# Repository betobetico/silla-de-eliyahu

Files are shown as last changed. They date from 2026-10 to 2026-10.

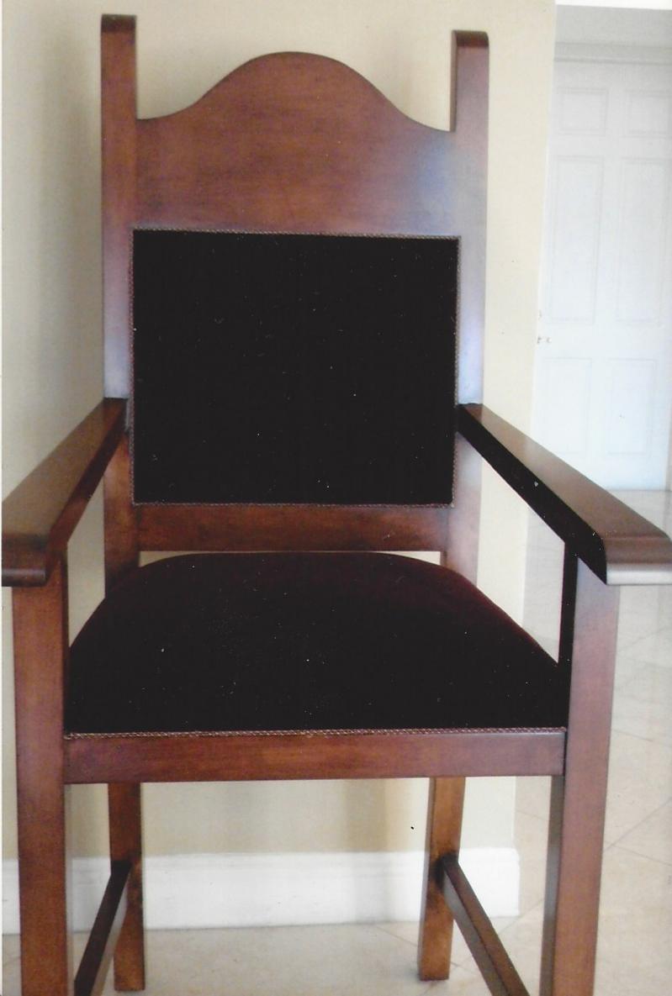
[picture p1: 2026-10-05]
plano/original/foto-frente.jpg

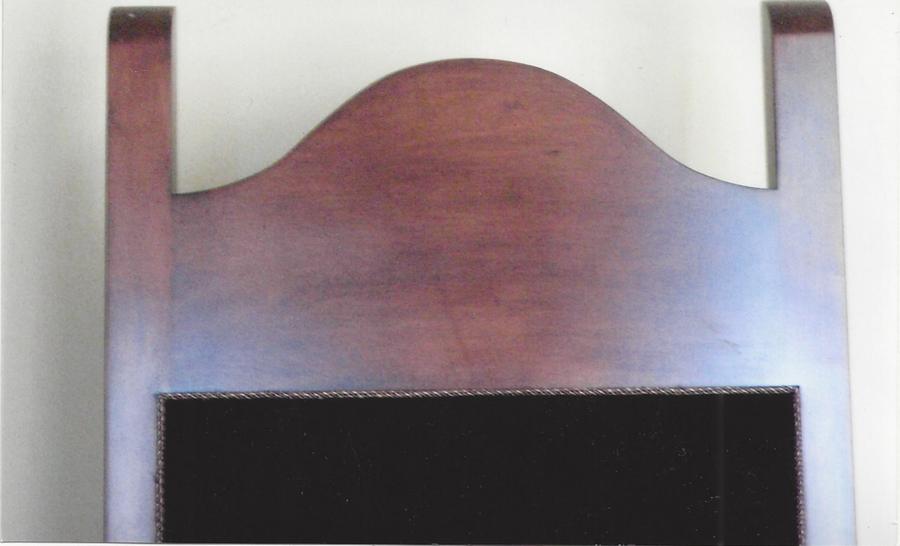
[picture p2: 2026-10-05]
plano/original/foto-copete.jpg

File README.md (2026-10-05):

# La silla de Eliyahu de Isaac Garzón Serfaty z”l

> זה כסא אליהו הנביא זכור לטוב
> *Esta es la silla del profeta Elías, recordado para bien.*

En cada brit milá se reserva una silla para el profeta Eliyahu. Isaac Garzón Serfaty z”l, «tito Isaque», quería hacer sillas como esta para que cada sinagoga pudiera tener la suya. Dejó el plano dibujado a lápiz. Este repositorio lo pasa a CAD para que cualquiera pueda llevárselo a un carpintero.

**Web: [sillaeliyahu.vercel.app](https://sillaeliyahu.vercel.app)** · [English](README.en.md)

> **Antes de cortar**, que un carpintero revise el plano y las seis cotas por validar de [`plano/DUDAS.md`](plano/DUDAS.md). Las medidas salen del dibujo a lápiz de Isaac y de dos fotos: la silla donada todavía no se ha medido.

## Descargas

| Fichero | Para qué |
|---|---|
| [`plano/silla-de-eliyahu.dxf`](plano/silla-de-eliyahu.dxf) | AutoCAD, LibreCAD, FreeCAD… Alzado, vista lateral, planta y copete, acotados en centímetros a escala 1:1 |
| [`plano/silla-de-eliyahu.pdf`](plano/silla-de-eliyahu.pdf) | Tres hojas A3 para imprimir: vistas a 1:10, detalles a 1:4 y despiece |
| [`plano/despiece.csv`](plano/despiece.csv) | Lista de cortes: pieza, cantidad, sección, largo visible y largo de corte con las espigas |
| [`plano/silla.json`](plano/silla.json) | Las medidas de cada pieza: la fuente de la que sale todo lo demás |
| [`plano/DUDAS.md`](plano/DUDAS.md) | **Las cotas que hay que revisar antes de cortar** |
| [`plano/original/`](plano/original/) | Los escaneos: el plano a lápiz de Isaac, la plantilla de las letras y dos fotos de una silla hecha |

## Medidas principales

| | cm |
|---|---|
| Alto total | 164,5 (ver D1) |
| Asiento | 70 (78 con el cojín) |
| Brazos | 101 detrás · 95 en la punta · vuelan 10 por delante de la pata |
| Ancho · fondo | 65 · 59 (69 con los brazos) |
| Postes y patas | 5 × 5 |
| Chambranas y travesaños | 5 × 3 |
| Brazos | 8 × 4 |
| Copete | 26 × 3, con la inscripción grabada por delante |
| Reposapiés | 67 × 13 × 2,5, a 12 del suelo, cajeado en las patas |
| Esterillado | listones de 3 × 1 al ras de las chambranas |

Son 37 piezas de 17 tipos. El plano no indica la especie de madera.

## Antes de cortar

El plano de Isaac no lo dice todo. Hay seis puntos en los que faltaba una cota o dos no cuadraban, y en cada uno se ha tomado una decisión. Están explicados en [`plano/DUDAS.md`](plano/DUDAS.md). Los dos que más cambian la silla:

- **D1 · Alto total.** El alzado lateral suma 159 y el trasero, 164,5. Se han respetado las piezas del trasero, con el respaldo de 45,5, y los postes miden 164,5.
- **D6 · Reposapiés.** En el plano va entero por delante de las patas. Como es el escalón natural para subirse a un asiento de 70, pisar su borde puede volcar la silla. Se ha retrasado: queda cajeado en las patas y apoyado en un travesaño.

En el DXF, las letras van en contornos (capa `LETRAS`, en Frank Ruhl Libre), listas para una fresadora o un láser. El texto editable está en la capa `LETRAS_TEXTO`, apagada, porque no todos los programas lo pintan de derecha a izquierda. Para grabar la caligrafía de Isaac, calca la plantilla original.

Si tienes una silla hecha con este plano, sus medidas resolverían las dudas: abre un *issue* con ellas.

## Cómo está hecho

Todo sale de un único fichero de medidas, [`plano/silla.json`](plano/silla.json). Cada pieza lleva su caja en centímetros (`x` ancho, `y` fondo con 0 en la trasera, `z` alto), su sección, sus espigas y el origen de cada cota: `plano` (escrita por Isaac), `deducido` (sale de sumar o restar cotas) o `supuesto` (elegido para que se pueda construir).

```bash
python3 -m venv .venv && .venv/bin/pip install -r plano/requirements.txt
.venv/bin/python plano/generar.py
```

`generar.py` comprueba que las cotas cuadran (alto total, asiento, ancho, fondo, la pata contra el brazo…) y genera el DXF, el PDF, el despiece y `DUDAS.md`. Si una comprobación falla, termina con error.

La web (`web/`, Next.js + three.js) dibuja la silla en 3D a partir del mismo `silla.json`, así que un cambio de medida llega también al dibujo:

```bash
cd web && npm install && npm run dev
```

## Licencia

El plano, las medidas, los dibujos y los textos tienen licencia [CC BY 4.0](https://creativecommons.org/licenses/by/4.0/deed.es): se pueden copiar, modificar y vender, siempre que se cite a **Isaac Garzón Serfaty z”l**. El código tiene licencia MIT ([`LICENSE-CODE`](LICENSE-CODE)). La fuente Frank Ruhl Libre de `plano/fuentes/` tiene licencia SIL OFL 1.1 ([`OFL.txt`](plano/fuentes/OFL.txt)).

## Haz la tuya

Yo no puedo hacer sillas para todo el mundo. Pero cualquiera puede coger este plano, llevárselo a un carpintero y hacer la silla para su sinagoga. Si eso pasa, yo habré cumplido mi parte y tito Isaque, su mitzvá: que haya una silla de Eliyahu en cada brit milá y se pueda cumplir la mitzvá de la circuncisión.

— Alberto Benbunan Garzón, sobrino de Isaac

La silla que se hizo con este plano en 2016-2017 está en la sinagoga Or Hayeladim de Madrid. La historia, con fotos, está en la web.

## Dónde hay una silla de Isaac

| Sinagoga | Ciudad | |
|---|---|---|
| — | Caracas (Venezuela) | Donada por Isaac |
| — | Porlamar, isla de Margarita (Venezuela) | Donada por Isaac |
| Skylake | Miami (Estados Unidos) | Donada por Isaac |
| Or Hayeladim | Madrid (España) | Julio de 2017, hecha con su plano |

Si sabes de otra, o si haces la tuya, [abre un *issue*](https://github.com/betobetico/silla-de-eliyahu/issues/new) y la añadimos.

## Créditos

- Plano y primera silla: Isaac Garzón Serfaty z”l.
- Primer CAD del plano: Acacia Waich. El de este repositorio se ha rehecho a partir del suyo.
- Carpintero de la silla de Or Hayeladim: Mateo Bonilla, que aparece en las fotos del taller. En las de la silla terminada aparece Alberto Benbunan Garzón.
- Las fotos de `web/public/historia/` son de sus autores y no entran en la licencia CC BY.

*En memoria de Isaac Garzón Serfaty z”l.*

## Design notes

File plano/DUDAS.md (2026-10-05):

# Cotas por validar

El plano de Isaac no lo dice todo. Donde faltaba una cota o dos no cuadraban, se ha tomado una decisión.
Este fichero se genera desde `silla.json`: para cambiar algo, edita ese fichero y ejecuta `python plano/generar.py`.

## D1 · Alto total: 159 o 164,5

El alzado lateral suma 20 + 5 + 40 + 5 + 27 + 4 + 58 = 159, que coincide con la cota total que escribió Isaac. El trasero suma 20 + 5 + 40 + 5 + 8 + 8 + 45,5 + 15 + 18 = 164,5. Una de las dos cadenas tiene una cota mal.

- **Se ha hecho:** Se respetan las medidas de las piezas del alzado trasero, con el respaldo de 45,5 como está escrito: los postes miden 164,5 y el «58» del lateral pasa a 63,5. Las proporciones de las fotos encajan mejor con 45,5 que con un respaldo recortado.
- **Alternativa:** Mantener 159 acortando de 18 a 12,5 lo que el poste asoma sobre el hombro del copete. Medir la silla donada lo resuelve

## D2 · Ancho: 65 por fuera

El alzado trasero acota 65 entre las caras exteriores de los postes. El «66 interno» del croquis de los brazos está dibujado a lo largo del brazo: es su largo, no un ancho.

- **Se ha hecho:** 65 por fuera y 55 por dentro. Las fotos dan un interior de ese orden.

## D3 · El vuelo del brazo

El «10» del lateral está entre la cara delantera de la pata y la punta del brazo: el brazo vuela 10 cm. Con «66 interno» como largo, la punta queda entre 7 y 12 cm por delante de la pata. En la foto parece que vuela unos 5.

- **Se ha hecho:** Vuelo de 10 y brazo de 64 visibles desde el poste. Cortar los brazos a 70 y recortar la punta en obra. El ensanche de 8 a 10 en la punta es un supuesto sacado de las fotos.
- **Alternativa:** Vuelo de 5, como parece en la foto

## D4 · Chambrana delantera y esterillado

El plano dice que lleva esterillado al ras de la chambrana, pero no dibuja la chambrana delantera ni cómo se apoyan los listones.

- **Se ha hecho:** Chambrana delantera igual que la trasera y dos listones de 2 × 2 por dentro de las laterales para apoyar 11 listones de 3 × 1 de 55 cm, entre los postes y las patas.
- **Alternativa:** Listones de delante a atrás, apoyados en la chambrana delantera y la trasera

## D5 · Las letras

La plantilla está a tamaño real: los números 32, 26 y 11,5 que la acompañan (69,5 en total) son los largos de las tres filas de la hoja, y a esa escala las letras miden entre 3,5 y 3,9 cm, lo mismo que dice la nota «letras bajas 3,5 cm». La escala se ha deducido así, no medido: el escaneo no trae resolución.

- **Se ha hecho:** Letras de 3,5 cm en dos líneas centradas: la de arriba mide unos 47 cm y la de abajo unos 22, con unos 4 cm de margen a cada lado en los 55 del copete. Antes de grabar, comprobar en papel que la línea de arriba cabe.

## D6 · Reposapiés y vuelco

En el plano el reposapiés va entero por delante de las patas, a 12 del suelo (Isaac escribe 12 y 13: 12 parece la altura y 13 el fondo de la tabla). Es el escalón natural para subirse a un asiento de 70, y si un adulto pisa su borde delantero puede volcar la silla hacia delante.

- **Se ha hecho:** Se retrasa: la tabla va de 7 cm por detrás a 6 cm por delante de la cara de las patas, cajeada alrededor de ellas, sobre un travesaño de 5 × 3 entre las patas y dos ménsulas cortas.
- **Alternativa:** El reposapiés de Isaac, entero por delante, con un travesaño bajo su arista trasera y la advertencia de no subirse por él

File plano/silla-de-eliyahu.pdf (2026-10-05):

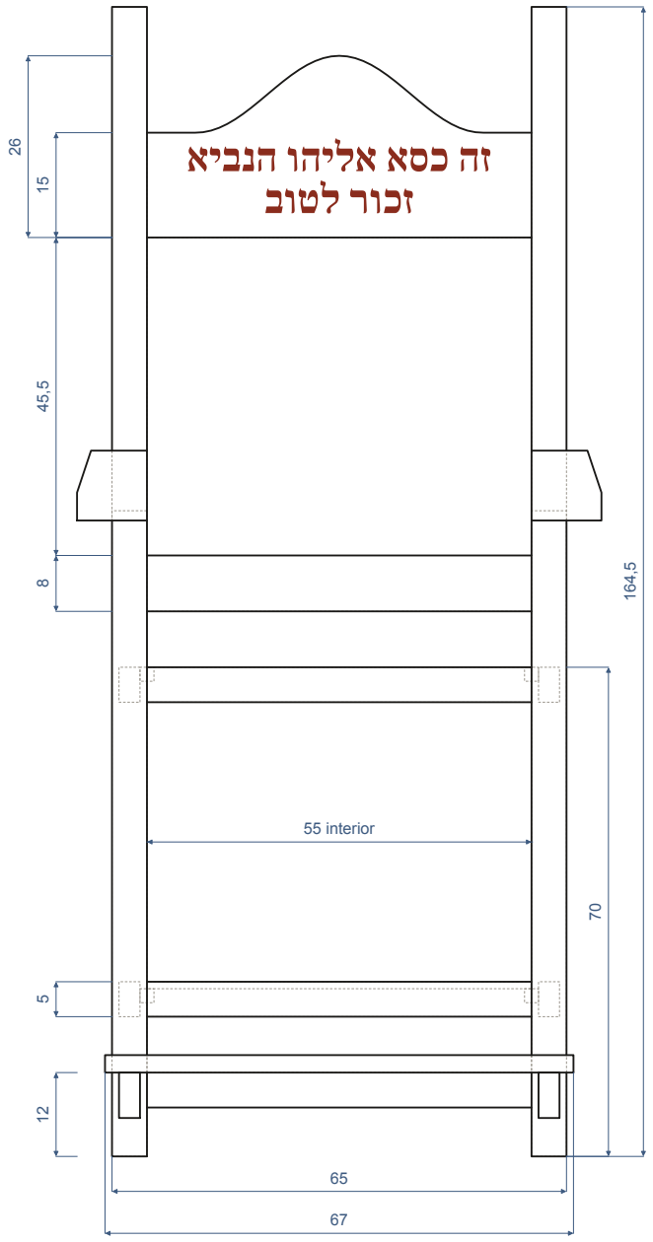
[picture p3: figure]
55 interior

ALZADO FRONTAL

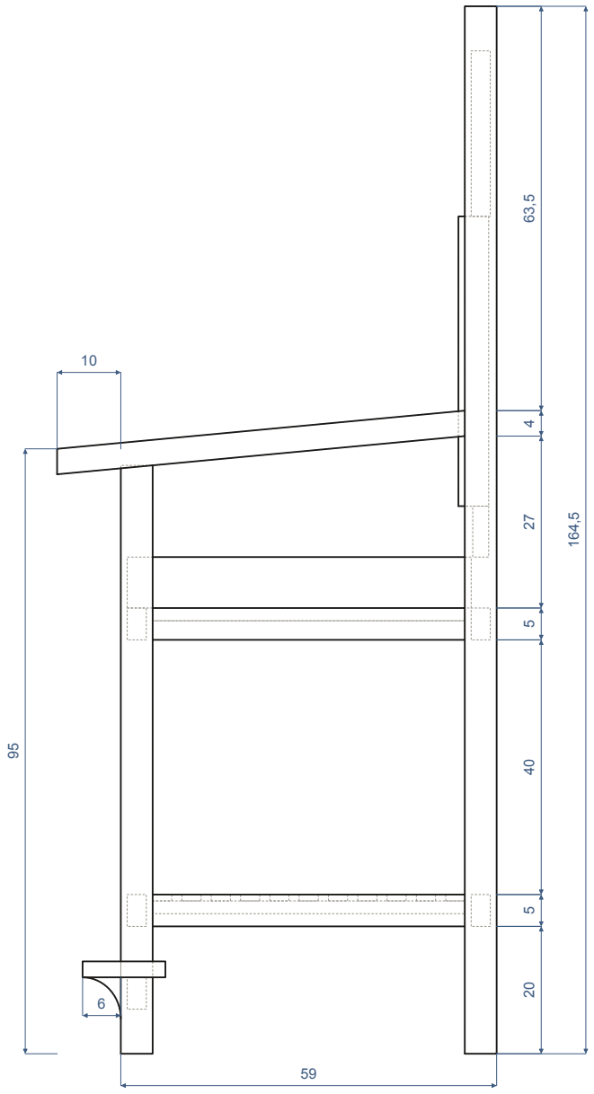
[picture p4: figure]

← FRENTE

VISTA LATERAL

# Silla de Eliyahu (Kisé Eliyahu) de Isaac Garzón Serfaty z”l

Alzado y vista lateral · escala 1:10 en A3 · cotas en cm · sistema europeo

CC BY 4.0 · atribución: Isaac Garzón Serfaty z”l · github.com/betobetico/silla-de-eliyahu

AVISO

Antes de cortar, que un carpintero revise este plano y las seis cotas por validar de la hoja 4. Las medidas de la silla donada todavía no se han tomado.

NOTAS

- Postes y patas 5×5 · chambranas y travesaños 5×3
- Brazos 8×4 · copete 26×3 · travesaño bajo del respaldo 8×2,5
- Reposapiés 67×13×2,5 cajeado en las patas (D6)
- Esterillado de listones 3×1 al ras de las chambranas
- Espigas de 2,5 cm en chambranas, travesaño del respaldo y copete; de 3,5 en travesaños del asiento, brazos y patas. Donde dos espigas entran en el mismo poste a la misma altura, se cortan a inglete. Grueso de espiga: 1 cm en piezas de 3
- Inscripción grabada en la cara delantera del copete: calcar la plantilla original, que está a tamaño real
- Cajas de postes y patas y despiece: hoja 3 · planta y detalles: hoja 2
- Cotas por validar antes de cortar: hoja 4 (D1-D6)

Dibujado a partir del plano a lápiz de Isaac Garzón Serfaty
z”l y del primer CAD, de Acacia Waich. Ante la duda, manda una silla de verdad.

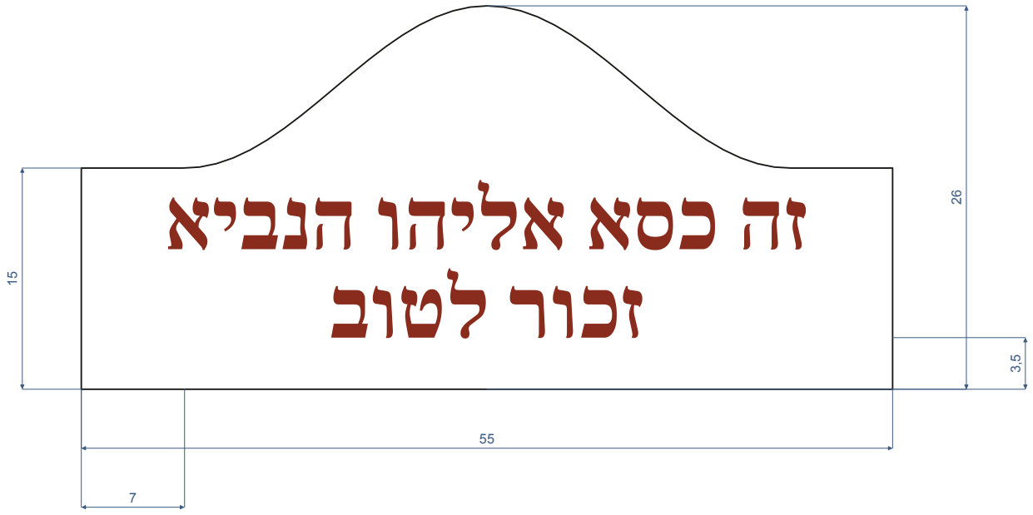
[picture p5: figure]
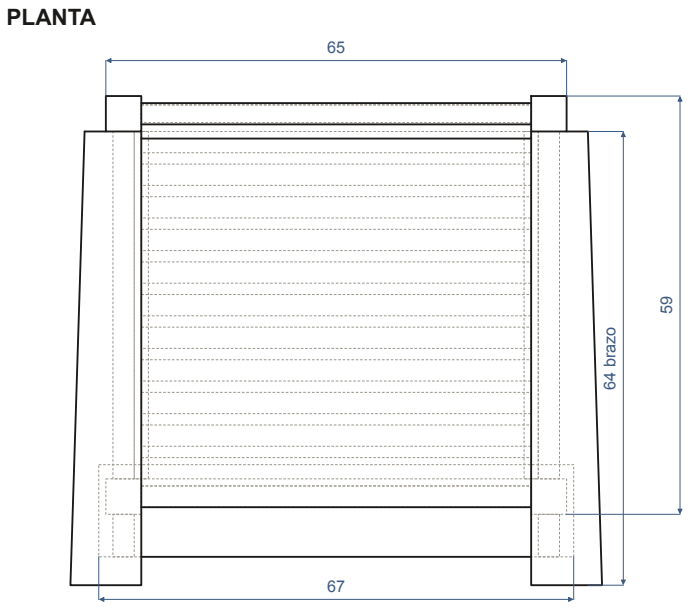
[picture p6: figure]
64 brazo; PLANTA

FRENTE ↓

DETALLE DEL COPETE

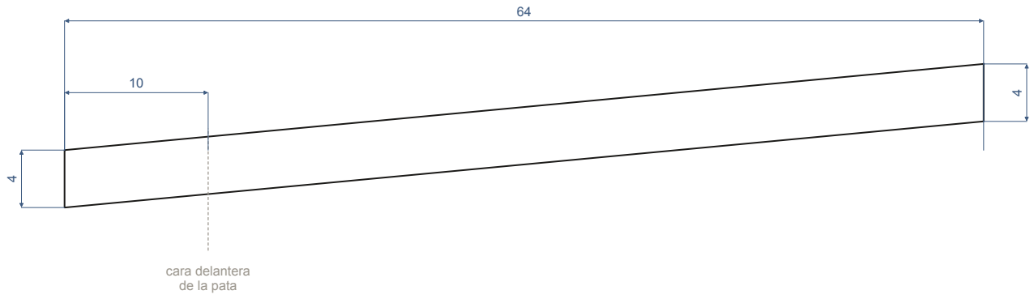
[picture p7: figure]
cara delantera de la pata

8
10

BRAZO · perfil (arriba) y planta (abajo) · la arista recta va hacia dentro

Cortar a 70 y recortar la punta en obra (D3). 101 en el poste, 95 en la punta.

pata

6

6,5

12

13

6

REPOSAPIÉS Y MÉNSULA (D6)

# Planta y detalles

Planta a 1:10 · copete, brazo y ménsula a 1:4 · cotas en cm

chambranas · 20-25

travesaños del asiento · 65-70 travesaño bajo del respaldo · 78-86

brazo · 97-101

copete (hombro) · 131,5-146,5

164,5

POSTE

travesaño del reposapiés · 7-12

chambranas · 20-25

travesaños del asiento · 65-70 92,4

PATA

# Cajas y despiece

Alturas de las cajas en postes y patas a 1:10 · largo de corte = largo visible + espigas

Pieza | Cant. | Sección | Visible | Espiga | Corte | Origen
Poste trasero | 2 | 5 × 5 | 164,5 | — | 164,5 | deducido
Pata delantera | 2 | 5 × 5 | 92,4 | 1 × 3,5 | 95,9 | deducido
Chambrana lateral | 2 | 5 × 3 | 49 | 2 × 2,5 | 54 | plano
Chambrana delantera y trasera | 2 | 5 × 3 | 55 | 2 × 2,5 | 60 | plano / supuesto
Listón del esterillado | 11 | 3 × 1 | 55 | — | 55 | plano
Listón soporte del esterillado | 2 | 2 × 2 | 49 | — | 49 | supuesto
Travesaño lateral del asiento | 2 | 5 × 3 | 49 | 2 × 3,5 | 56 | plano
Travesaño delantero y trasero del asiento | 2 | 5 × 3 | 55 | 2 × 3,5 | 62 | deducido
Listón de apoyo del asiento | 2 | 2 × 2 | 49 | — | 49 | supuesto
Asiento tapizado | 1 | tablero 55 × 54 × 1,5 + espuma | 55 | — | 55 | deducido
Travesaño inferior del respaldo | 1 | 8 × 2,5 | 55 | 2 × 2,5 | 60 | plano
Respaldo tapizado | 1 | tablero 1,5 + espuma | 55 | — | 55 | plano
Copete con dibujo | 1 | 26 × 3 | 55 | 2 × 2,5 | 60 | plano
Brazo | 2 | 8 × 4 | 64,3 | 1 × 3,5 | 70 | plano
Reposapiés | 1 | 13 × 2,5 | 67 | — | 67 | supuesto
Travesaño del reposapiés | 1 | 5 × 3 | 55 | 2 × 2,5 | 60 | supuesto
Ménsula del reposapiés | 2 | 6 × 6,5 × 3 | 6,5 | — | 6,5 | deducido

Espigas de 2,5 cm en chambranas, travesaño del respaldo y copete; de 3,5 en travesaños del asiento, brazos y patas.

Donde dos espigas entran en el mismo poste a la misma altura, se cortan a inglete. Grueso de espiga: 1 cm en piezas de

3.

Además: listones de 2×2 para fijar el respaldo tapizado por detrás, y cuatro escuadras de madera en las esquinas del

bastidor del asiento.

# Cotas por validar antes de cortar

Donde el plano de Isaac no lo dice o dos cotas no cuadran, la decisión tomada y la alternativa

D1 · Alto total: 159 o 164,5

El alzado lateral suma 20 + 5 + 40 + 5 + 27 + 4 + 58 = 159, que coincide con la cota total que escribió Isaac. El trasero suma 20 + 5 + 40 + 5 + 8 + 8 + 45,5 + 15 +

18 = 164,5. Una de las dos cadenas tiene una cota mal.

Se ha hecho: Se respetan las medidas de las piezas del alzado trasero, con el respaldo de 45,5 como está escrito: los postes miden 164,5 y el «58» del lateral pasa a

63,5. Las proporciones de las fotos encajan mejor con 45,5 que con un respaldo recortado.

Alternativa: Mantener 159 acortando de 18 a 12,5 lo que el poste asoma sobre el hombro del copete. Medir la silla donada lo resuelve

D2 · Ancho: 65 por fuera

El alzado trasero acota 65 entre las caras exteriores de los postes. El «66 interno» del croquis de los brazos está dibujado a lo largo del brazo: es su largo, no un

ancho.

Se ha hecho: 65 por fuera y 55 por dentro. Las fotos dan un interior de ese orden.

D3 · El vuelo del brazo

El «10» del lateral está entre la cara delantera de la pata y la punta del brazo: el brazo vuela 10 cm. Con «66 interno» como largo, la punta queda entre 7 y 12 cm

por delante de la pata. En la foto parece que vuela unos 5.

Se ha hecho: Vuelo de 10 y brazo de 64 visibles desde el poste. Cortar los brazos a 70 y recortar la punta en obra. El ensanche de 8 a 10 en la punta es un supuesto

sacado de las fotos.

Alternativa: Vuelo de 5, como parece en la foto

D4 · Chambrana delantera y esterillado

El plano dice que lleva esterillado al ras de la chambrana, pero no dibuja la chambrana delantera ni cómo se apoyan los listones.

Se ha hecho: Chambrana delantera igual que la trasera y dos listones de 2 × 2 por dentro de las laterales para apoyar 11 listones de 3 × 1 de 55 cm, entre los postes

y las patas.

Alternativa: Listones de delante a atrás, apoyados en la chambrana delantera y la trasera

D5 · Las letras

La plantilla está a tamaño real: los números 32, 26 y 11,5 que la acompañan (69,5 en total) son los largos de las tres filas de la hoja, y a esa escala las letras

miden entre 3,5 y 3,9 cm, lo mismo que dice la nota «letras bajas 3,5 cm». La escala se ha deducido así, no medido: el escaneo no trae resolución.

Se ha hecho: Letras de 3,5 cm en dos líneas centradas: la de arriba mide unos 47 cm y la de abajo unos 22, con unos 4 cm de margen a cada lado en los 55 del copete.

Antes de grabar, comprobar en papel que la línea de arriba cabe.

D6 · Reposapiés y vuelco

En el plano el reposapiés va entero por delante de las patas, a 12 del suelo (Isaac escribe 12 y 13: 12 parece la altura y 13 el fondo de la tabla). Es el escalón

natural para subirse a un asiento de 70, y si un adulto pisa su borde delantero puede volcar la silla hacia delante.

Se ha hecho: Se retrasa: la tabla va de 7 cm por detrás a 6 cm por delante de la cara de las patas, cajeada alrededor de ellas, sobre un travesaño de 5 × 3 entre las

patas y dos ménsulas cortas.

Alternativa: El reposapiés de Isaac, entero por delante, con un travesaño bajo su arista trasera y la advertencia de no subirse por él

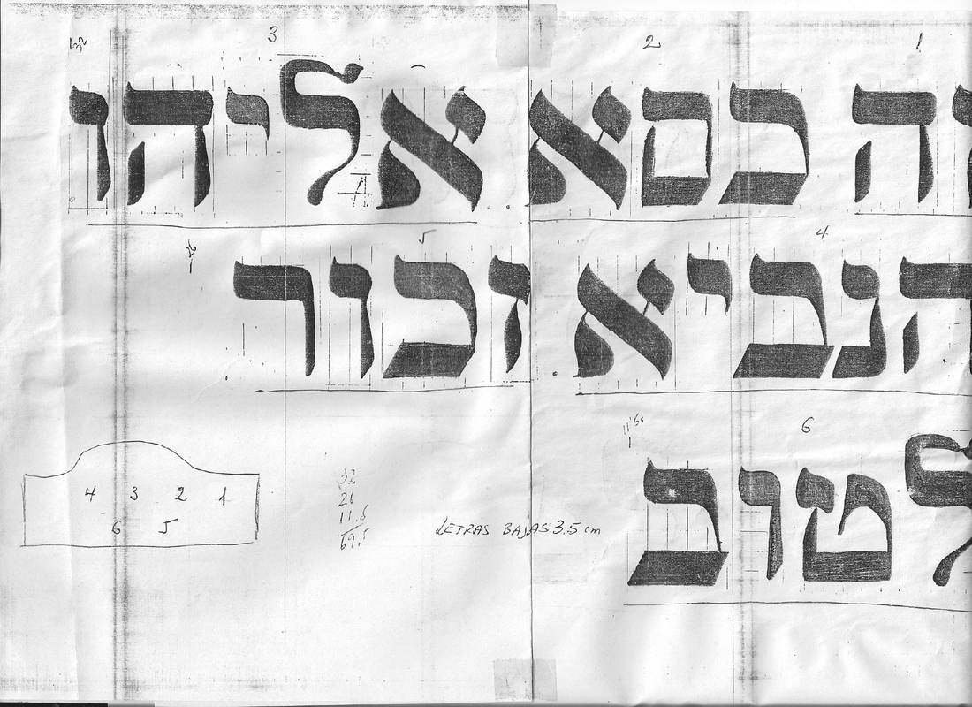
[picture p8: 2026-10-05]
plano/original/plantilla-letras.jpg

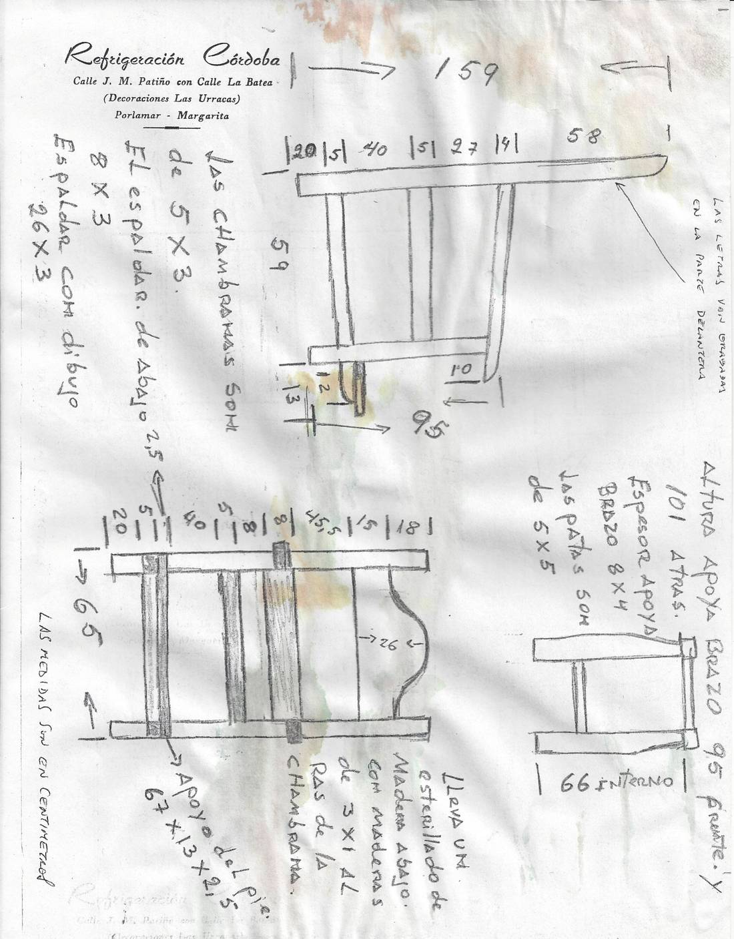
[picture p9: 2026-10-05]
plano/original/plano-isaac.jpg

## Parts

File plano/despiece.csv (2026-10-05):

pieza | piece | cantidad | seccion_cm | largo_visible_cm | largo_corte_cm | espigas | espiga_cm | origen | nota
Poste trasero | Back post | 2 | 5 × 5 | 164.5 | 164.5 | 0 | 0 | deducido | 164,5 de alto (ver D1). Remate superior con la arista delantera redondeada (r ≈ 2 cm)
Pata delantera | Front leg | 2 | 5 × 5 | 92.4 | 95.9 | 1 | 3.5 | deducido | Hombro inclinado como el brazo: 92,4 detrás y 91,9 delante. Mejor con espiga pasante acuñada por la cara de arriba del brazo
Chambrana lateral | Side stretcher | 2 | 5 × 3 | 49 | 54.0 | 2 | 2.5 | plano
Chambrana delantera y trasera | Front and back stretcher | 2 | 5 × 3 | 55 | 60.0 | 2 | 2.5 | plano / supuesto | El plano no la dibuja; hace falta para cerrar el marco del esterillado
Listón del esterillado | Slatted shelf slat | 11 | 3 × 1 | 55 | 55.0 | 0 | 0 | plano | 11 listones de 55 cm, separados 1,6 cm, con la cara de arriba al ras de las chambranas (z = 25)
Listón soporte del esterillado | Shelf cleat | 2 | 2 × 2 | 49 | 49.0 | 0 | 0 | supuesto | Encolado y atornillado por dentro de la chambrana lateral
Travesaño lateral del asiento | Side seat rail | 2 | 5 × 3 | 49 | 56.0 | 2 | 3.5 | plano
Travesaño delantero y trasero del asiento | Front and back seat rail | 2 | 5 × 3 | 55 | 62.0 | 2 | 3.5 | deducido
Listón de apoyo del asiento | Seat cleat | 2 | 2 × 2 | 49 | 49.0 | 0 | 0 | supuesto | Encolado y atornillado por dentro del travesaño lateral del asiento
Asiento tapizado | Upholstered seat | 1 | tablero 55 × 54 × 1,5 + espuma | 55 | 55.0 | 0 | 0 | deducido | Tablero de contrachapado de 1,5 sobre los travesaños delantero y trasero y sobre dos listones de apoyo; espuma y tapizado hasta z = 78. Se recomiendan cuatro escuadras de madera en las esquinas del bastidor
Travesaño inferior del respaldo | Lower back rail | 1 | 8 × 2,5 | 55 | 60.0 | 2 | 2.5 | plano | El plano pone «2,5» y debajo «8×3»: si se compra a 3, el grueso de la caja en el poste es 3. En el alzado trasero sus testas asoman: pueden ser espigas pasantes (largo 65)
Respaldo tapizado | Upholstered back | 1 | tablero 1,5 + espuma | 55 | 55.0 | 0 | 0 | plano | Alto 45,5, como en el alzado trasero. Se atornilla por detrás a listones de 2 × 2 encolados en los postes, el travesaño inferior y el copete
Copete con dibujo | Crest rail | 1 | 26 × 3 | 55 | 60.0 | 2 | 2.5 | plano | Recto 7 cm junto a cada poste y luego un arco en campana hasta 26 en el centro. Lleva grabada la inscripción en la cara delantera. Va 1 cm por detrás de la cara delantera de los postes; en la foto parece enrasado
Brazo | Arm | 2 | 8 × 4 | 64.3 | 70 | 1 | 3.5 | plano | Arista interior enrasada con la cara interior del poste: vuela 3 por fuera. Entra en el poste a 97-101 y vuela 10 por delante de la pata. Ensanche de 8 a 10 en la punta: supuesto, por las fotos. Cortar a 70 y recortar la punta en obra (D3)
Reposapiés | Footrest | 1 | 13 × 2,5 | 67 | 67.0 | 0 | 0 | supuesto | Retrasado por seguridad (D6): de y 52 a 65, cajeado 5 × 5 alrededor de cada pata. Cara de abajo a 12 cm del suelo
Travesaño del reposapiés | Footrest rail | 1 | 5 × 3 | 55 | 60.0 | 2 | 2.5 | supuesto | Entre las patas delanteras, bajo el reposapiés (D6)
Ménsula del reposapiés | Footrest bracket | 2 | 6 × 6,5 × 3 | 6.5 | 6.5 | 0 | 0 | deducido | Escuadra con el lado de abajo en curva, atornillada por delante de la pata, bajo el vuelo del reposapiés

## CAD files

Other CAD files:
plano/silla-de-eliyahu.dxf

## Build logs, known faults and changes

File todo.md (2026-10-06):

# Pendientes técnicos

- [ ] Revisar las vulnerabilidades de dependencias: `npm ci` en Vercel informa de cinco de severidad alta (6-oct-2026). Identificar los paquetes y su alcance antes de actualizar; no ejecutar una corrección forzada sin revisar los cambios.

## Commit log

2026-10-05 La silla de Eliyahu de Isaac Garzón Serfaty z”l: plano CAD, despiece y web
    - plano/silla.json: fuente única de medidas, con el origen de cada cota y las dudas D1-D6
    - plano/generar.py: genera el DXF (letras en contornos), el PDF A3, el despiece y DUDAS.md, y comprueba cotas y solapes
    - web/: Next.js + three.js, la silla en 3D que se despieza con el scroll, la historia de cómo se hizo y el plano para descargar, en español e inglés
    Plano y primera silla: Isaac Garzón Serfaty z”l. Primer CAD: Acacia Waich.
    [despiece.csv, silla-de-eliyahu.dxf]
2026-10-05 Sillas de Isaac: Caracas, Porlamar, Miami y Madrid, y su legado en la historia
    - Isaac donó sillas a sinagogas de Caracas, Porlamar y Miami; la de Or Hayeladim continúa su legado
    - Nueva sección con la lista y un enlace para avisar de otras sillas
    - Que cada uno haga la suya y multiplique su mitzvá
2026-10-05 Quita un estilo viejo que descuadraba la lista de sillas
2026-10-05 Retrato de tito Isaque en su historia y en la dedicatoria
2026-10-05 Retrato con marco blanco y algo girado; fuera la cara de la dedicatoria
2026-10-06 Añade el manuscrito de Tito Isaque y amplía el registro de sillas
2026-10-06 Recorta la vista del manuscrito y añade el enlace y la atribución en portada
